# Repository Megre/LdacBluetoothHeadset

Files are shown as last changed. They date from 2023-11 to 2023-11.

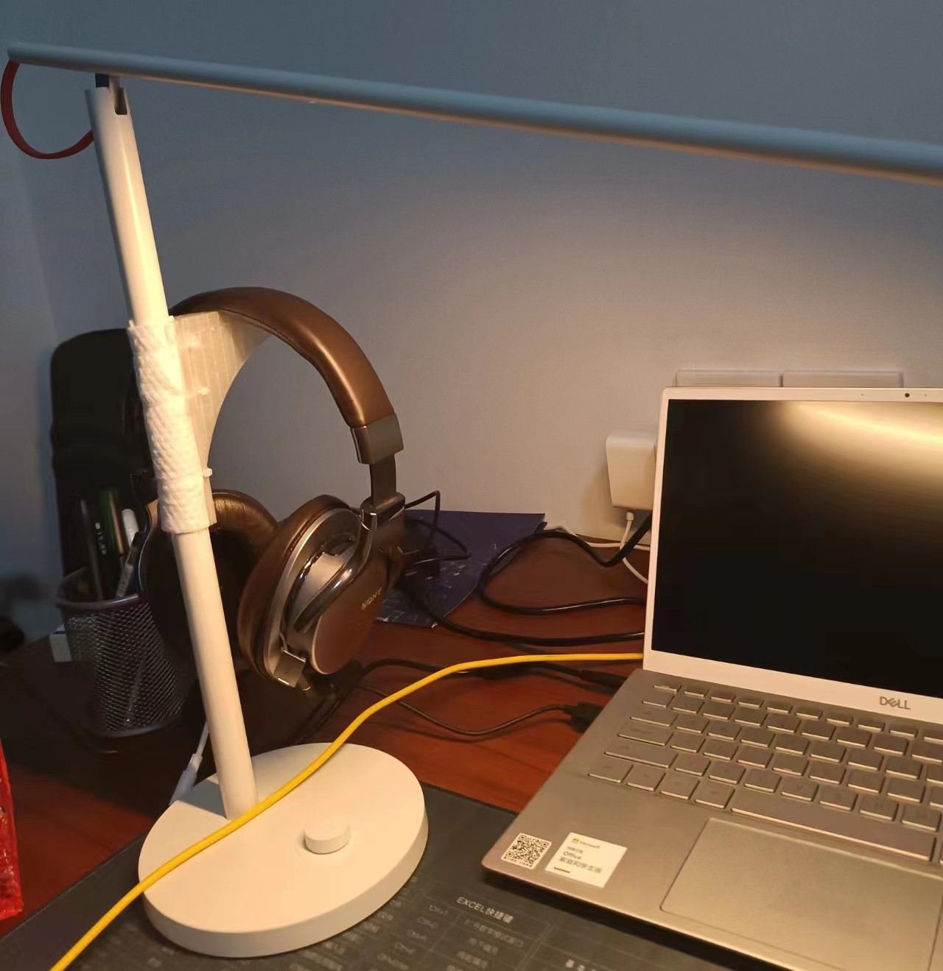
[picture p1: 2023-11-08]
Screenshots/微信图片_20231108110929.jpg

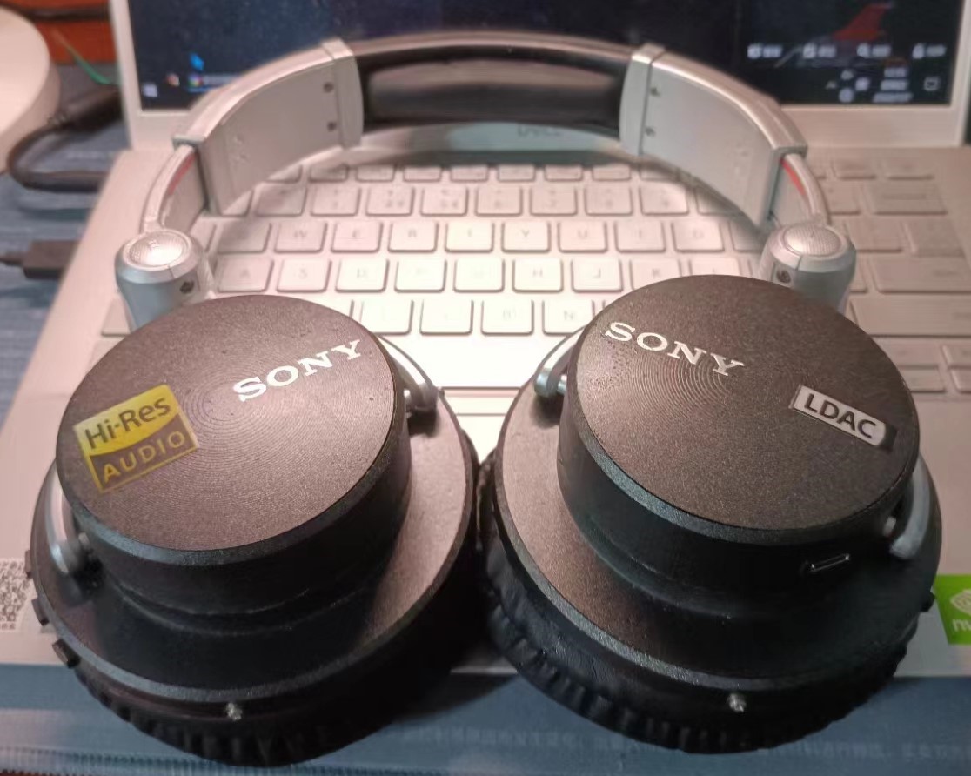
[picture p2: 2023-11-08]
Screenshots/微信图片_20231108110843.jpg

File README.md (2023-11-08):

微信图片_20231108110843

# 主要特点

- LDAC高清蓝牙协议（Sony开发的编码技术）

- 声音纯净，几乎无底噪
- 全包耳，不闻窗外事
- 可充电锂电池，超长待机
- 3D打印外壳（喷漆上色）

# 按键

3D外壳设计有三个按键：

- 上一曲（长按减小音量）
- 播放/暂停
- 下一曲（长按增大音量）

硬件连接参考下文[电路](#电路)。

# BOM

- [高通无损蓝牙模块](https://s.click.taobao.com/t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)（LDAC无模拟输出）
- [立体声数模转换器](https://s.click.taobao.com/t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)
- [40mm耳放单元](https://s.click.taobao.com/t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)
- [耳机头梁](https://s.click.taobao.com/t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)
- [5V锂电池](https://s.click.taobao.com/t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)
- [10cm海绵耳套](https://s.click.taobao.com/t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)
- [1mm调音棉](https://s.click.taobao.com/t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)
- [手机喇叭防尘网](https://s.click.taobao.com/t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)
- [自喷漆](https://s.click.taobao.com/t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)、[清漆](https://s.click.taobao.com/t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)
- [E8000胶水](https://s.click.taobao.com/t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)
- [M2*8螺丝](https://s.click.taobao.com/t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) 

# DIY Tips

## 电路

参考[网络上一篇帖子](https://baijiahao.baidu.com/s?id=1713677146849619172&wfr=spider&for=pc)，以及蓝牙模块说明。

3D模型可以容纳各模块飞线连接的尺寸。

如果后续升级这个项目，会设计印刷电路（上传了一些正在设计的电路图，尚未完成）。发展线路是：设计印刷电路+成品外壳。主要由于自己打印模型比较费事，外观又不如成品外壳精美。

## 3D模型



这套3D模型是用SketchUp设计的，主要是耳机单元的部分，头梁选用成品配件。

虽然SketchUp很容易上手，但使用下来遇到很多问题，例如模型不封闭、实体交并差等操作结果异常等。总体印象SketchUp更适合建筑模型草图，不适合精确的小尺寸模型。转到Rhino后没有遇到上述头疼的问题。

资源中包含了一个`耳机支架`的3D模型，与台灯绑定（参考`Screenshots`）。

自己打印3D模型，建议使用光固化打印机。堆叠技术打印机做出的模型表面比较粗糙，无法喷涂上色（或者需要补土打磨，比较耗功夫）。

## 喷漆

可选用自喷漆，完全满足上色需要。上色建议佩戴防毒面罩。

气压泵+喷笔的喷涂方式就比较专业了，如果非喷涂爱好者或者喷涂作业比较少，不建议选用这种方式。

## 组装

左耳和右耳各有三个螺丝孔，用螺丝连接耳机单元和其余部分。

其余部分用胶水固定。E8000属于慢干胶，涂胶后建议用夹具固定，再进行后续操作。

上盖可最后涂胶。待其他模块连接完毕，确定耳机发音正常后再封胶。

Logo贴纸：[Hi-Res](https://s.click.taobao.com/t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)、LDAC及[SONY](https://s.click.taobao.com/t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)标。SONY标仅为致敬LDAC蓝牙协议。贴纸资源在`Logo`文件夹，可交商家制作贴纸。喷漆后贴纸，再喷清漆保护。

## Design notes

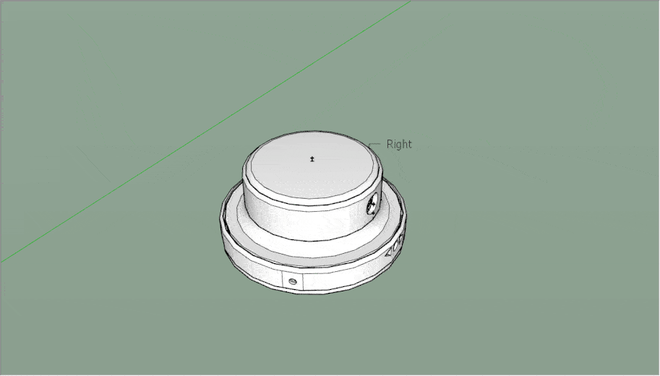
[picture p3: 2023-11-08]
3D/demo.gif

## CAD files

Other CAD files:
3D/bak/headset000.skp
3D/bak/headset001.skp
3D/bak/headset002.skp
3D/bak/headset003.skp
3D/bak/headset008.skp
3D/bracket.skp
